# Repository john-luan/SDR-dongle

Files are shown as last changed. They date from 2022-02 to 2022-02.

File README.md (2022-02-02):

# Description
This PCB project was initially started as an exercise of learning KiCAD.  
这个PCB最初是作为学习KiCAD的练习开始的。  
And it is currently working with KiCAD 6.99.  
目前在KiCAD 6.99下进行工作。  
It is composed of a ZYNQ of 7z010 or 7z020, a AD936x RF transceiver, and some necessary peripheral circuits.  
它包含一个7z010或者7z020，一个AD936x收发器和一些必要的外围电路。  
Right now, the main layout is completed, but probably, there will still be some major changes in the future.  
现在主要部分的布线已经完成，但可能后续仍然会有大的改动。  
Due to the restriction of the layers, there remain some problems, such as trance across a split plane.  
受限于板层，还有一些问题比如布线跨分割。  
Subsequently I may need to do some FEM simulations, but I don't know how to export the KiCAD project to formats recognized by FEM tools.  
后续我可能需要做一些FEM模拟，但是目前为止我还不知道怎么将KiCAD的文件导出成FEM工具识别的格式。  
I can only do this with my spare time, so it will not be fast.  
我只能用业余时间做这件事，所以不会很快。  

# Goals
 - Matching Arduino MKR's size
 - Using a USB-C or USB micro B connector
 - As cheap as possible, avoiding complex craft like HDI or blind hole
 - Fan out pins as many as possible
 - DDR3 clock up to 1066
 - Boot by SD-Card
 - Compatible with the ADALM pluto Firmware
 - Compatible with Openwifi

# Things not done yet
 - Refactoring the format of schematics 
 - USB C master and slaver selection circuit
 - Simulation to ensure DDR signal Integrity performance
 - Test TPS2121 hot swap function
...

# Compromise
 - Transceiver data traces routing
 - USB HS signal reference plane too narrow
 - USB ULPI not be tuned (length difference <10mm)
 - LTCC balun instead of broadband balun, BLNK2-252R+(2.4-2.5GHz)/TCO1-462+(3.3-5.9GHz) seems OK
 - All DDR3 VREF is generated by different partial voltage resistors
 - Cannot meet the analog pin multiplexing function of Arduino. there is a suitable device AD5593R, there is no space to add the chip on this board, maybe this device can used at next major version
 - SD Card and USB connector shield is connected to GND
 - Router trace in DIP pin gap
 - USB PHY SPK Pin is connected to GND, beacause the bottom reference plane is splited in chip area. connect to GND to creating current return path.
 - ZYNQ boot configure pin is fixed, its means bank0 IO voltage cannot be set to 3.3V
 - Via in pad

Current img
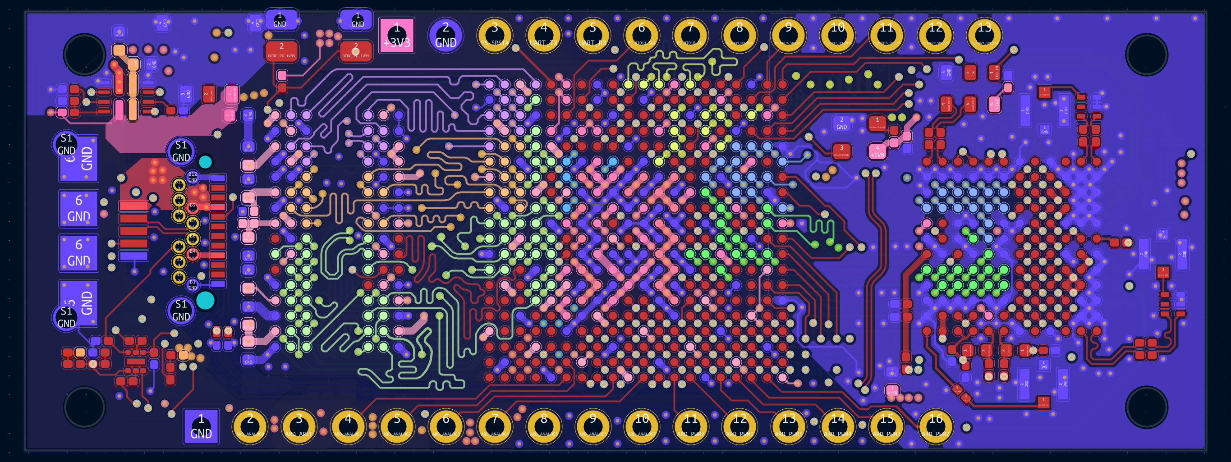
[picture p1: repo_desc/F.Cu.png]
F.Cu

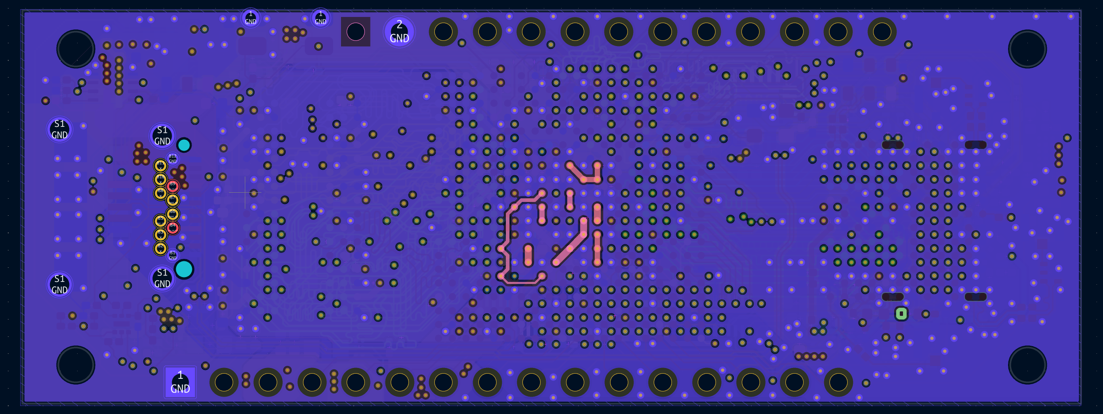
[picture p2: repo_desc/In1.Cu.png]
In1.Cu

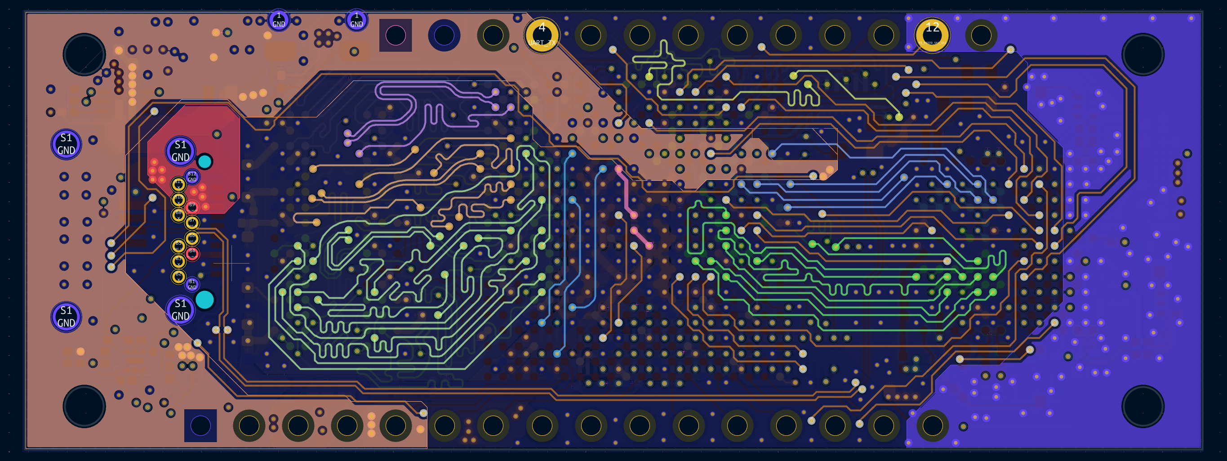
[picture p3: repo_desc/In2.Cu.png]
In2.Cu

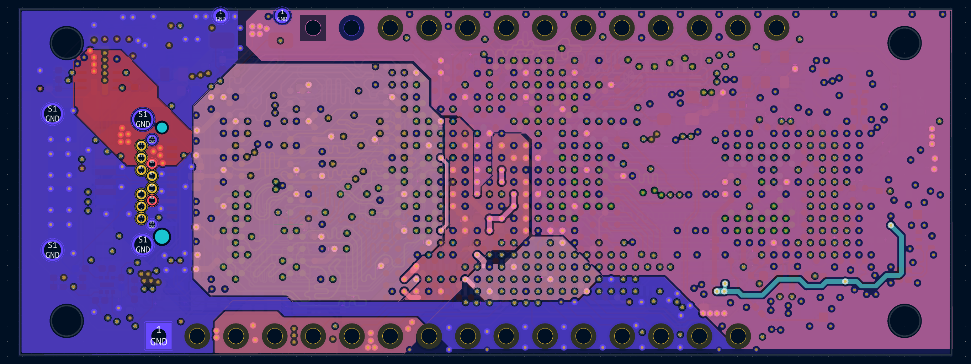
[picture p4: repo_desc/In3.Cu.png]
In3.Cu

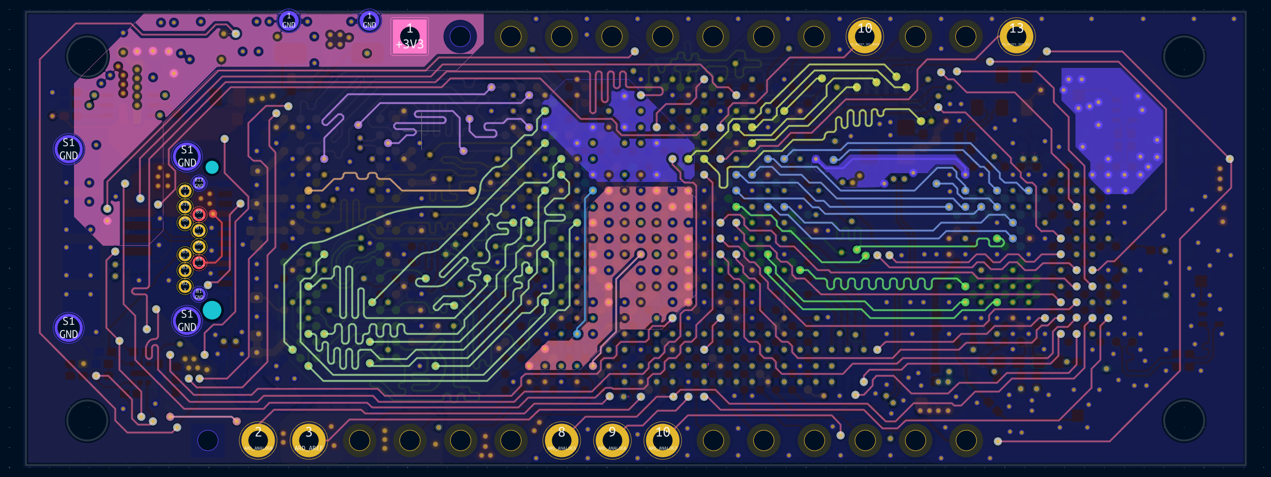
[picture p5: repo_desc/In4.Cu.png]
In4.Cu

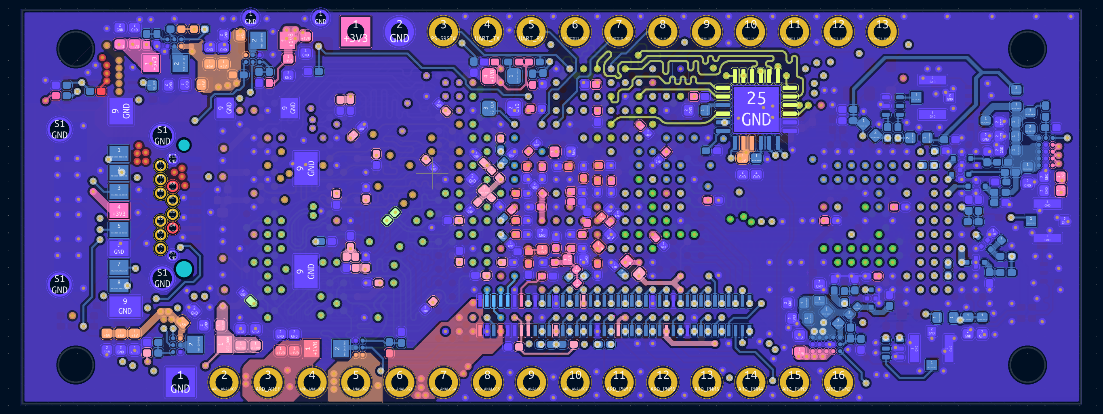
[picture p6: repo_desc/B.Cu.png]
B.Cu

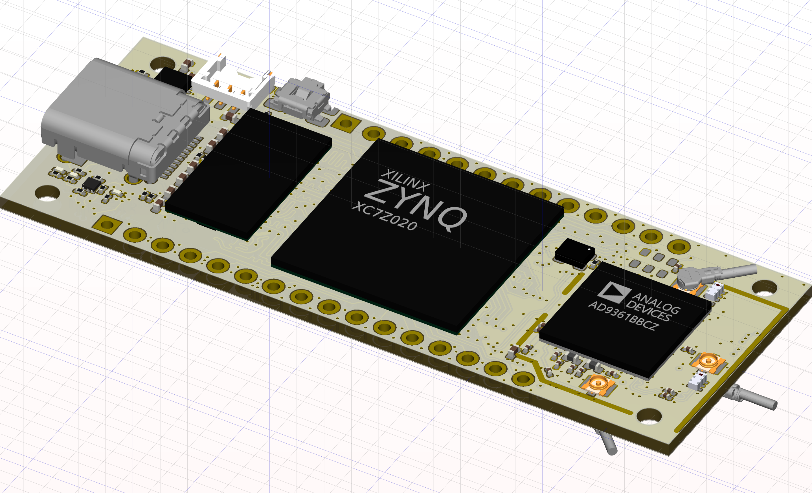
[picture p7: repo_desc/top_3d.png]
top_3D

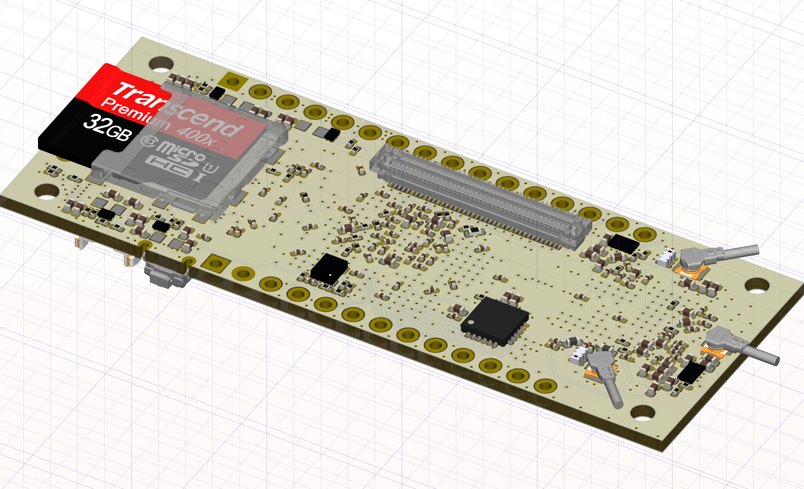
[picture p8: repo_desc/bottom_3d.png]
bottom_3d


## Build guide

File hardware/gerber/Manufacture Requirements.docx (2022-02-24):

# PCB工艺要求

层数：6

制作数量(拼板后)：20 pcs

最小线距 4mil；最小线宽 4mil

最小钻孔 0.2mm/0.4mm

钻孔类型：通孔

钻空孔处理方式：树脂塞孔表面镀平

孔壁铜厚：满足IPC 2级标准(min 18um; typ 20um)

表面处理：沉金

阻焊颜色：黑色亚光

丝印颜色：默认(白色)

阻焊桥处理：厂家根据实际加工能力可以不做小于工艺能力的阻焊桥，需要在工程确认时对光绘文件改动进行确认。

PCB尺寸（拼板后）：75.3mm×94.2mm

测试

四线过孔测试，飞针测试，通断测试等常规测试

提供出货报告

公差

板厚公差：±10%

板外形公差：±0.1mm

翘曲度（整版，以对角线参考）：≤1%

设计文件格式：Gerber文件

Gerber文件板层顺序和层压结构：

Gerber文件名 | 层功能描述/板材 | 厚度
xxx_Edge_Cuts.gbr | 工艺层:PCB外框
xxx_F_Silkscreen.gbr | 工艺层:顶层丝印 | | 3，4
xxx_F_Mask.gbr | 工艺层:顶层阻焊层掩膜 | 约1mil
xxx_F_Cu.gbr | 顶层铜层 | 1Oz | 完成铜厚>35um
Prepreg | 介质层/FR4 | 0.1mm | 1, 2
xxx_In1_Cu.gbr | 内部铜层 | 1Oz
Core | 介质层/FR4 | 0.2mm | 1, 2
xxx_In2_Cu.gbr | 内部铜层 | 1Oz
Prepreg | 介质层/FR4 | 0.127 | 1, 2
xxx_In3_Cu.gbr | 内部铜层 | 1Oz
Core | 介质层/FR4 | 0.2mm | 1, 2
xxx_In4_Cu.gbr | 内部铜层 | 1Oz
Prepreg | 介质层/FR4 | 0.1mm | 1, 2
xxx_B_Cu.gbr | 底层铜层 | 1Oz | 完成铜厚>35um
xxx_B_Mask.gbr | 工艺层:底层阻焊层掩膜 | 约1mil
xxx_B_Silkscreen.gbr | 工艺层:底层丝印 | | 3，4
总厚度 | | 1mm

1. 实际层压可以根据工艺微调，并在工程确认中反馈
2. 需要在工程确认中确认实际使用板材种类
3. 请勿在丝印层上添加厂家丝印，客编等源Gerber中没有的图形
4. 如果有丝印层和阻焊层开窗冲突的，去除冲突部分丝印层图案

钻孔文件：

xxx_NPTH.drl – NPTH钻孔

xxx_PTH.drl – PTH钻孔

xxx_NPTH_map.ps – NPTH钻孔描述

xxx_PTH_map.ps – PTH钻孔描述

钢网使用无边框钢片，将拼板后正反面（B_Paste层，F_Paste层）拼在同一张钢网上

钢网文件：

xxx_B_Paste - 底层钢网

xxx_F_Paste - 顶层钢网

拼板：

Gerber文件需要按板框标识层进行拼板，每4个单元板构成一个拼板。

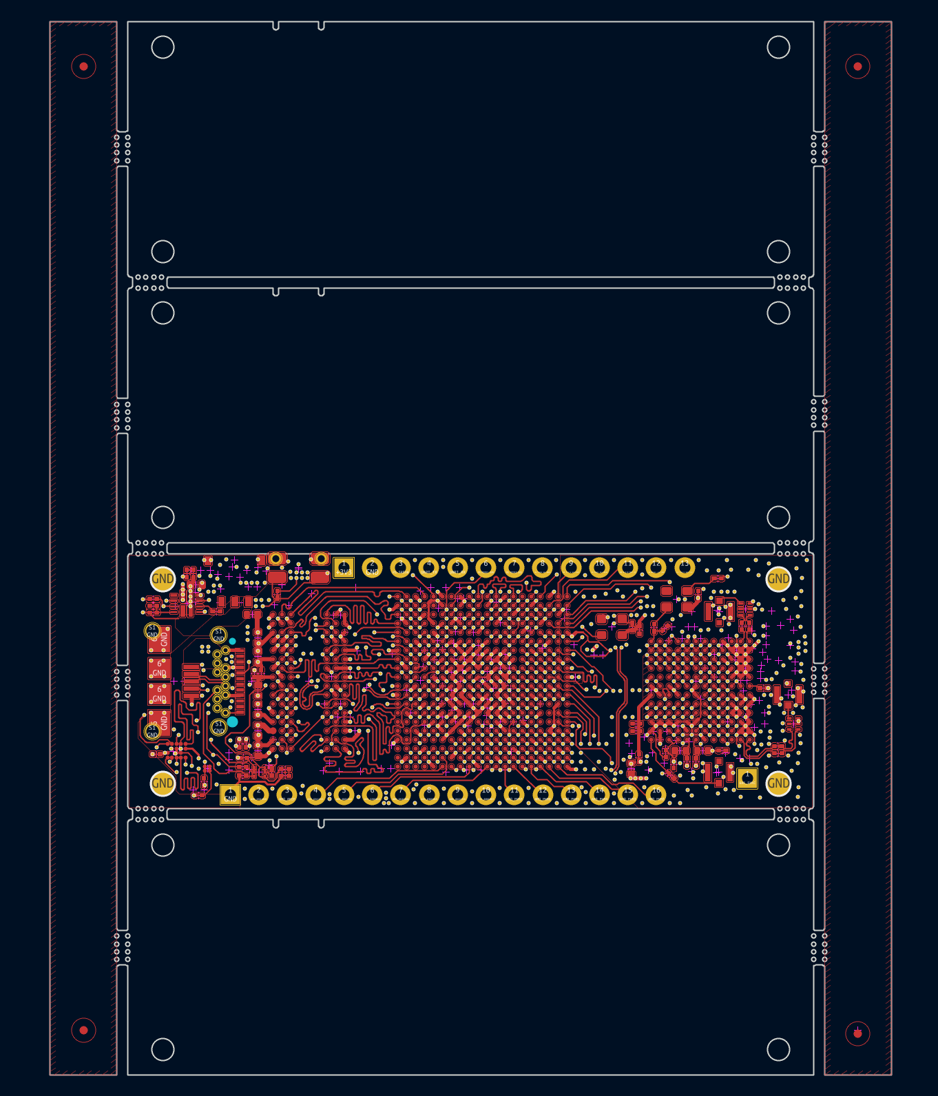
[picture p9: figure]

备注：

接受拼板打叉板，但需要按子板单元总数满足数量要求

需要工程/光绘确认完毕后再开料生产

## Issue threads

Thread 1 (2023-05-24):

咨询

ZhuYanzhen1, 2023-05-24:
请问此仓库中的电路有测试过吗，是否可以使用呢

john-luan, 2023-10-12:
> 请问此仓库中的电路有测试过吗，是否可以使用呢

R2是DDR RST的上拉，和SD座子冲突。但是实测DDR可以起。
C38要NC，不然可能RST后时序不对PS不启动。
MAX38904C买不到，TPS2121买不到
巴伦封装太小了，只能用LC巴伦，做不到高调谐带宽。

Linux能起，USB能读到，AD9361能读到。
9361 的移植没有做，要用的话需要检查CMOS连线和想办法做射频的测试。我自己review应该没啥问题

Closed 2023-10-12.

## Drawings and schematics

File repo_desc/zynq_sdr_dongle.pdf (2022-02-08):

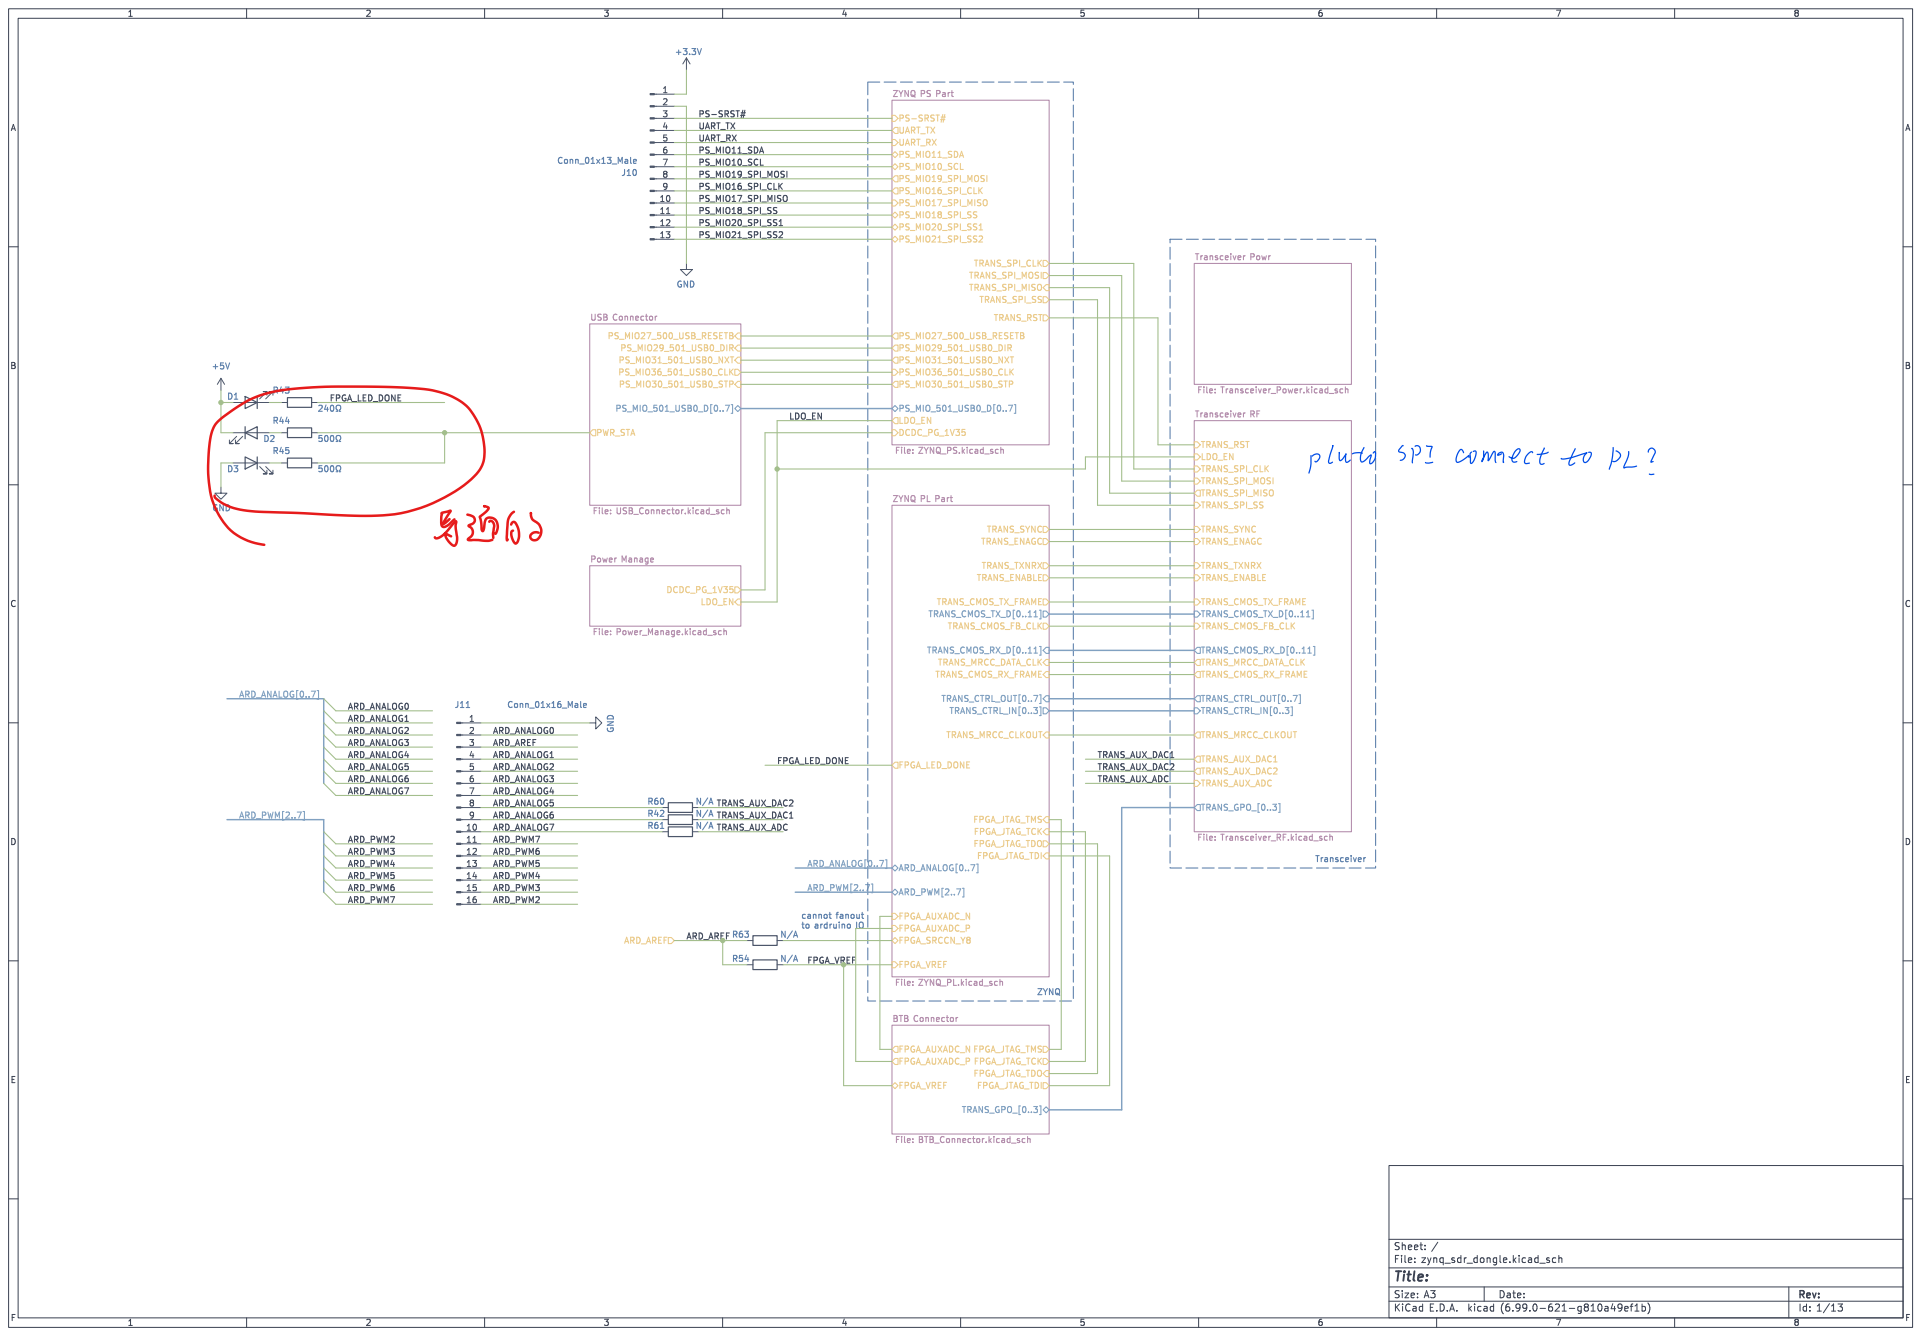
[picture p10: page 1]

PS_MIO27_500_USB_RESETB
ZYNQ PL Part File: ZYNQ_PL.kicad_sch FPGA_VREF

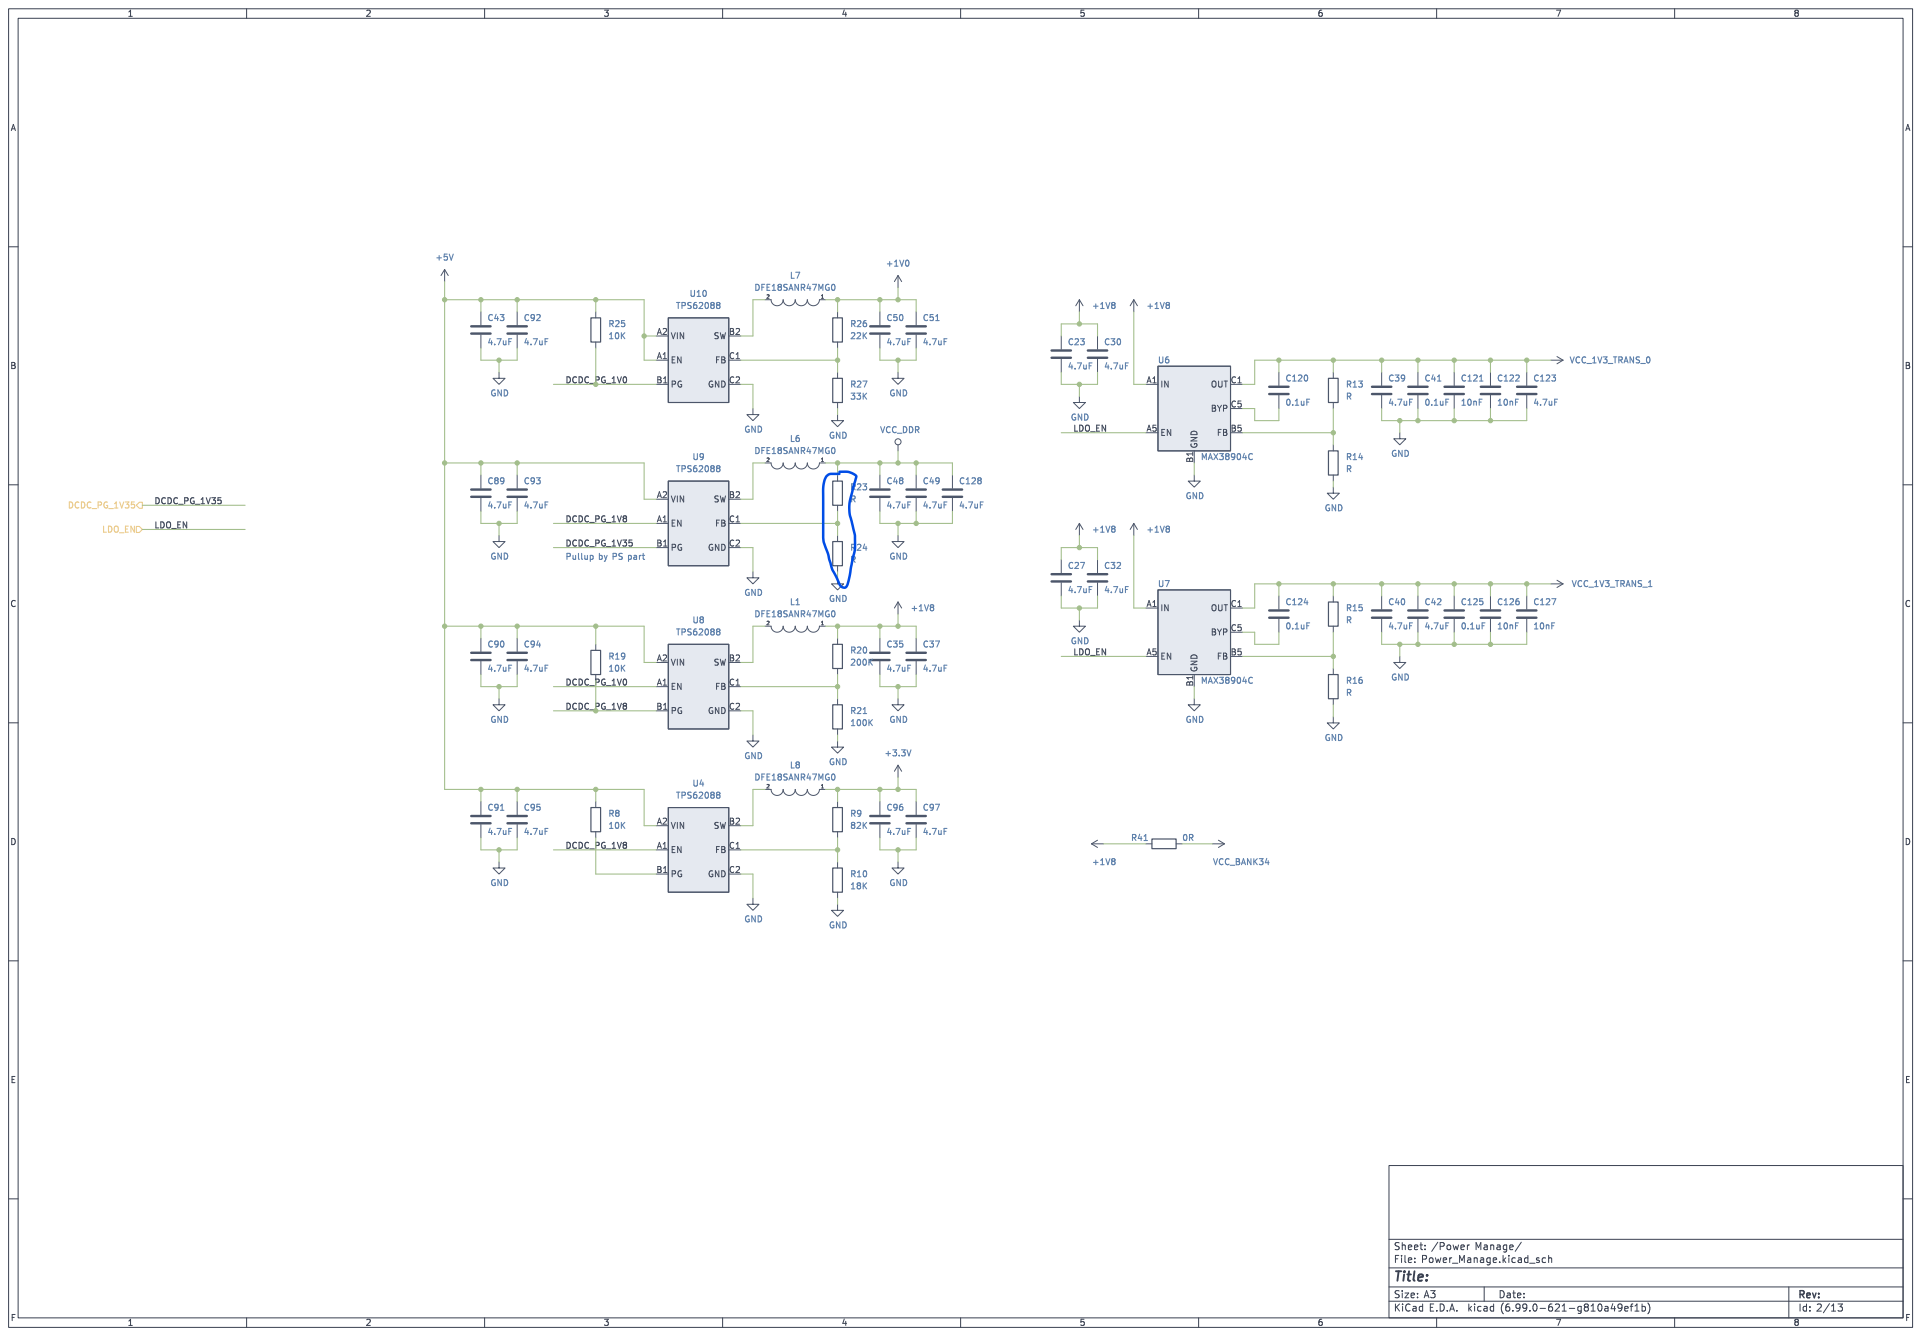
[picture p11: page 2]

Pullup by PS part

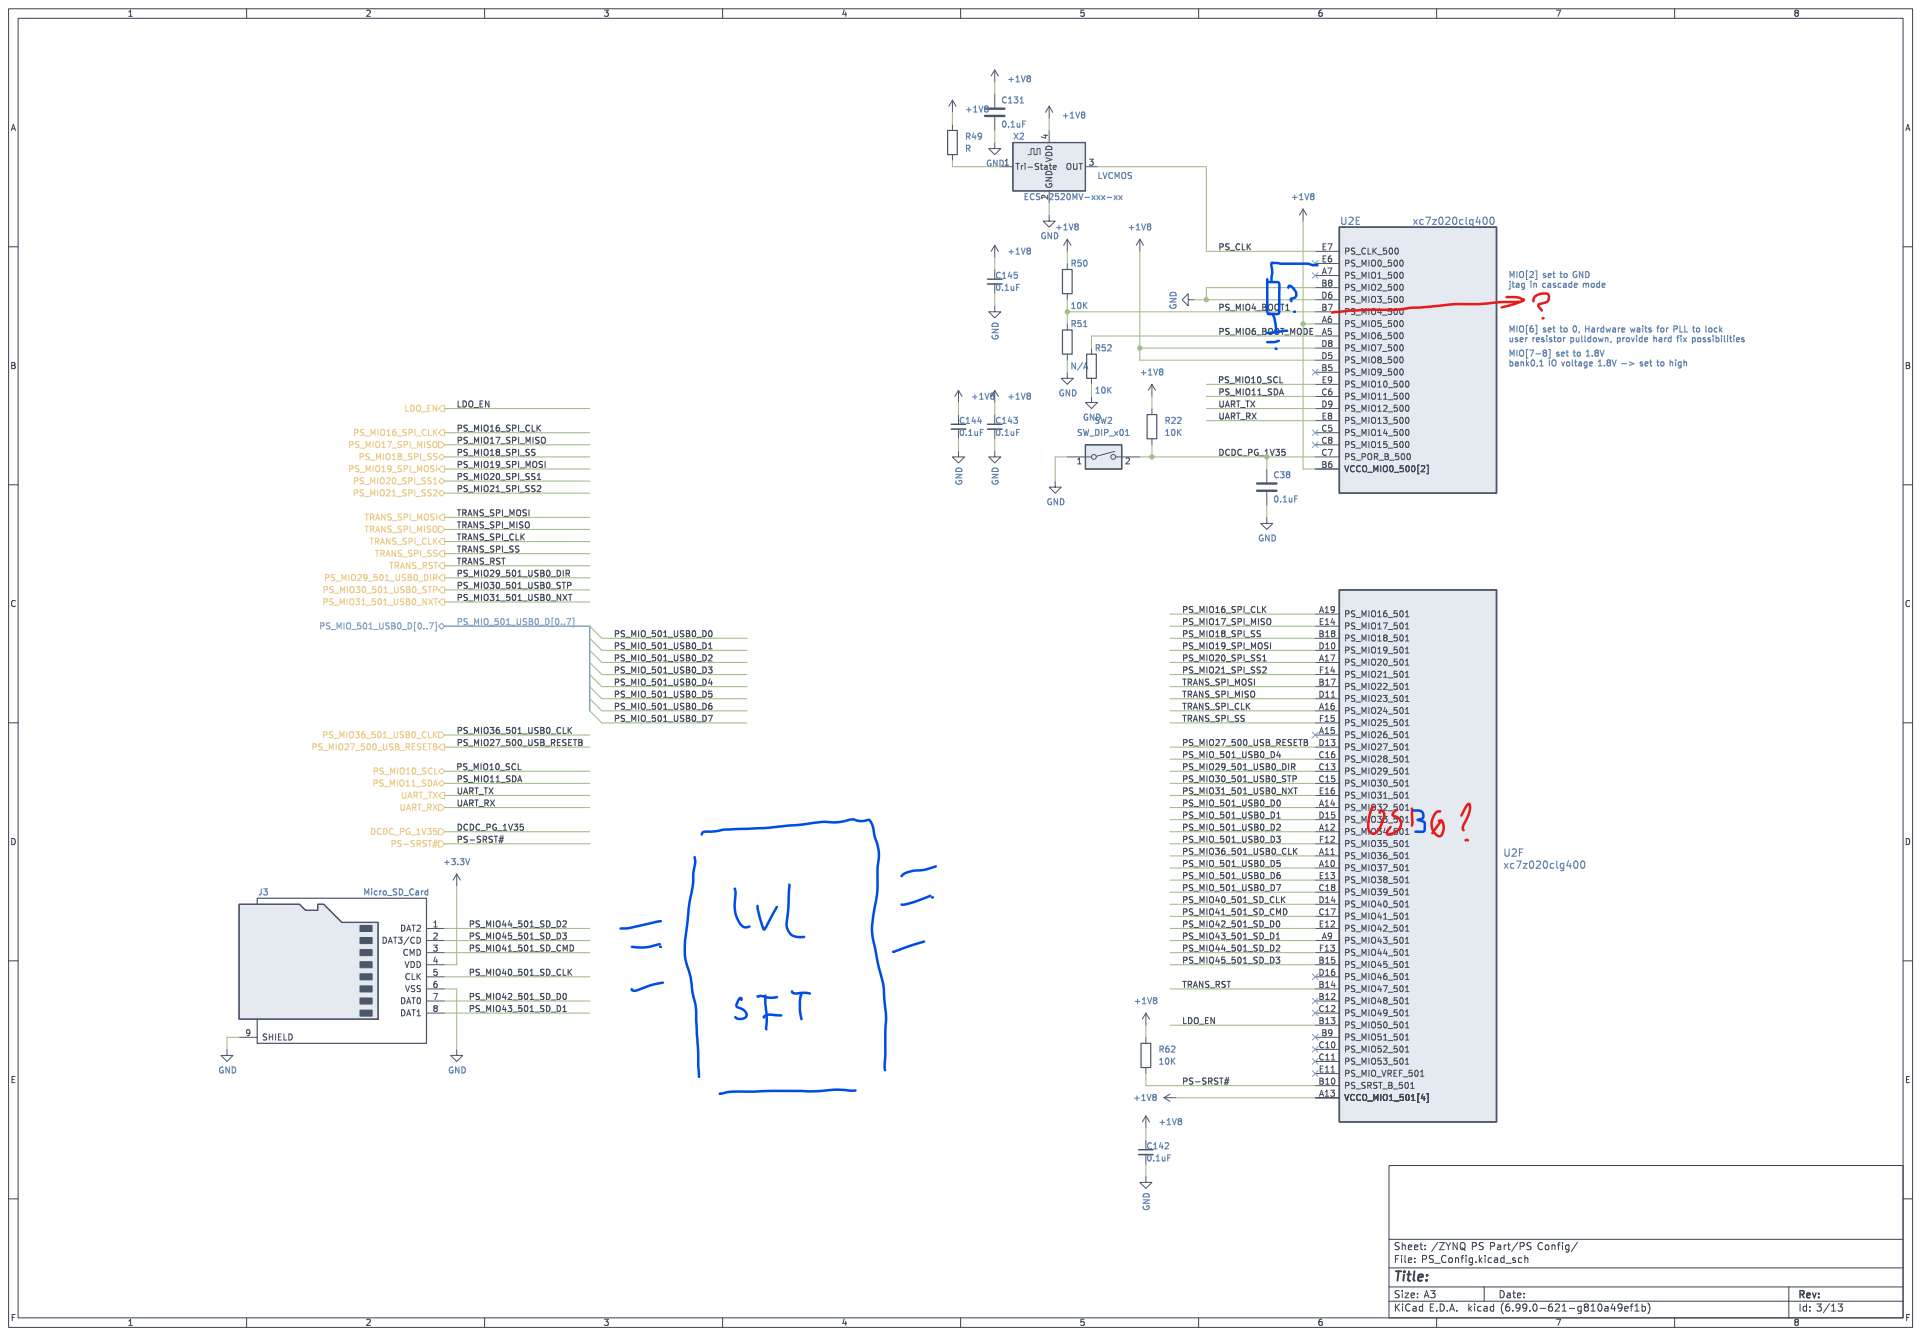
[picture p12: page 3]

MIO[2] set to GND
jtag in cascade mode

user resistor pulldown, provide hard fix possibilities
MIO[7-8] set to 1.8V
bank0,1 IO voltage 1.8V -> set to high

Sheet: /ZYNQ PS Part/PS Config/
File: PS_Config.kicad_sch
Id: 3/13 Title:

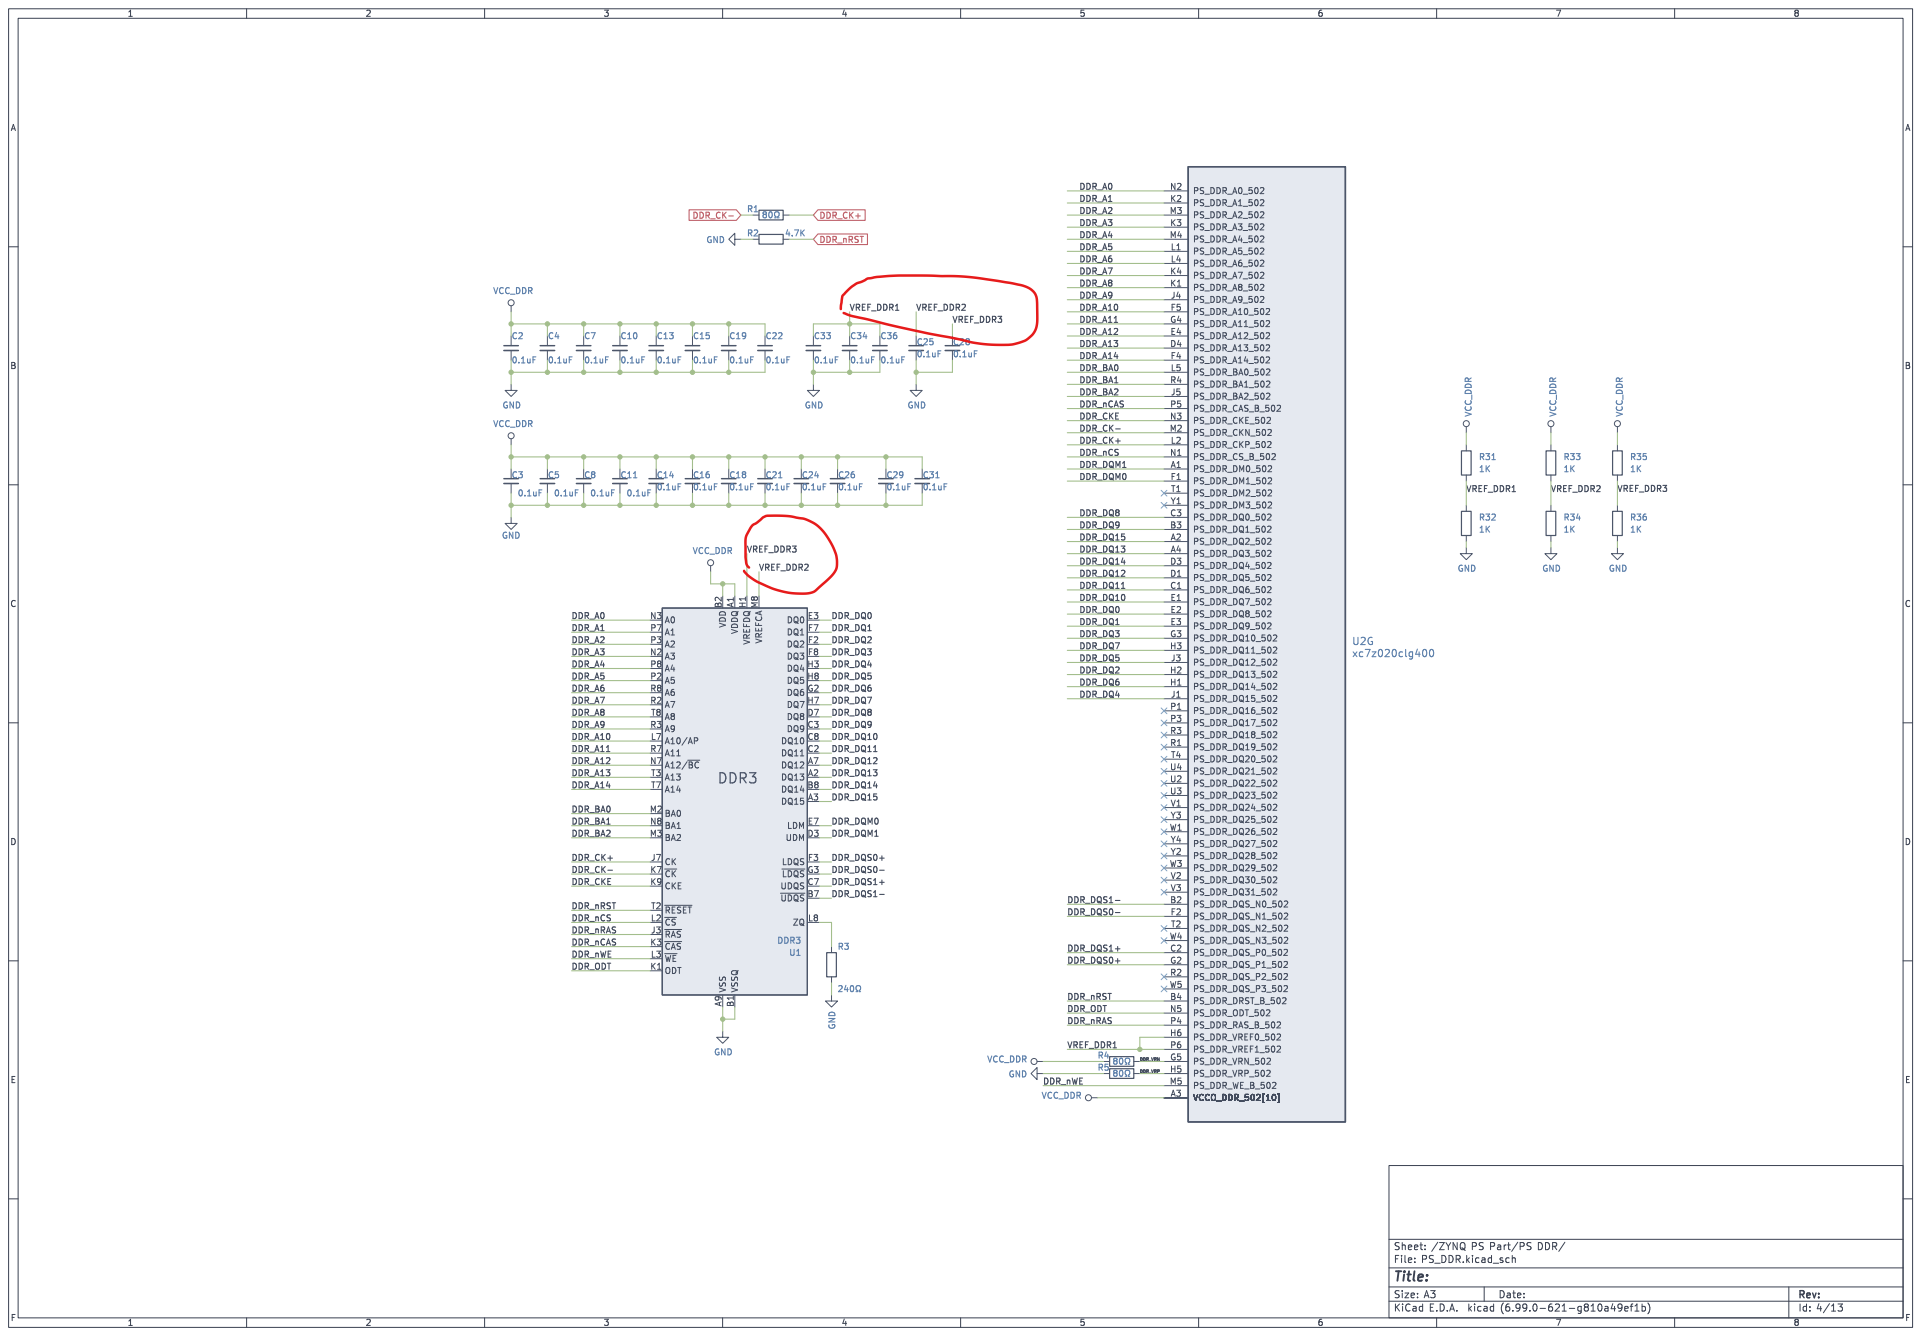
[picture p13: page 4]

Sheet: /ZYNQ PS Part/PS DDR/
File: PS_DDR.kicad_sch
Id: 4/13 Title:

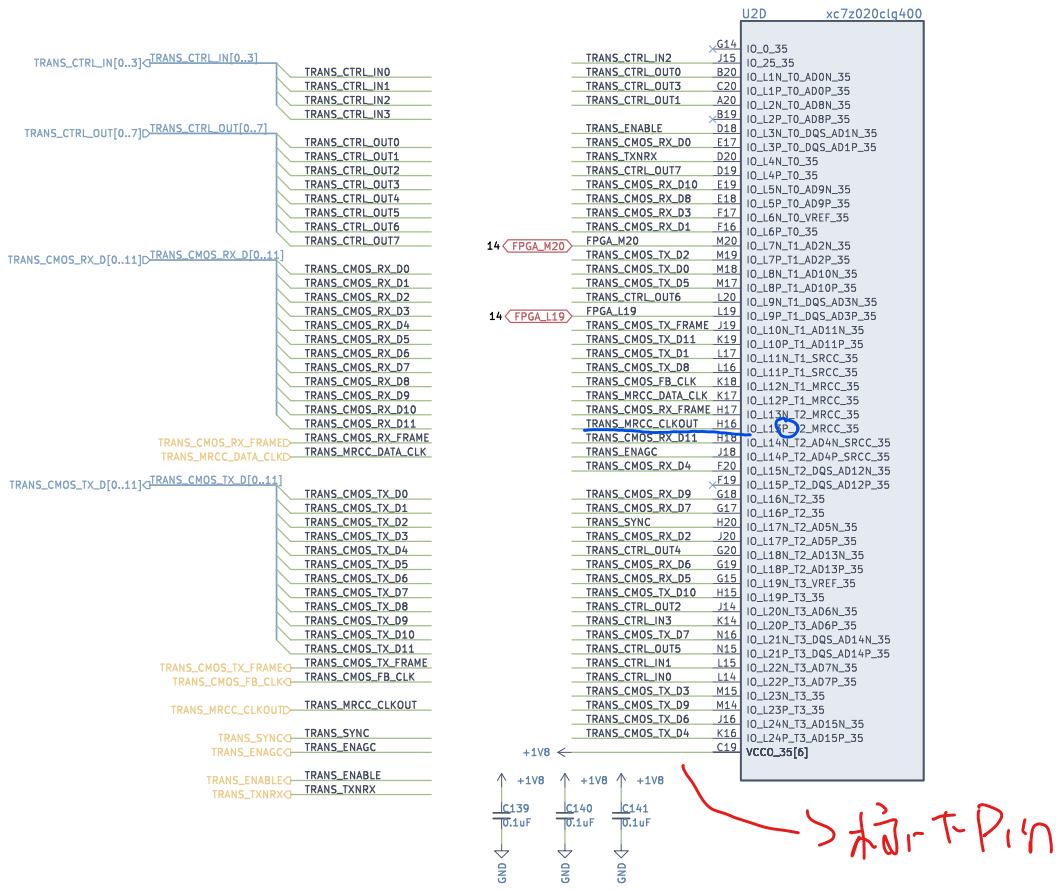
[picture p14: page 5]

Sheet: /ZYNQ PL Part/PL Transceiver/ GND

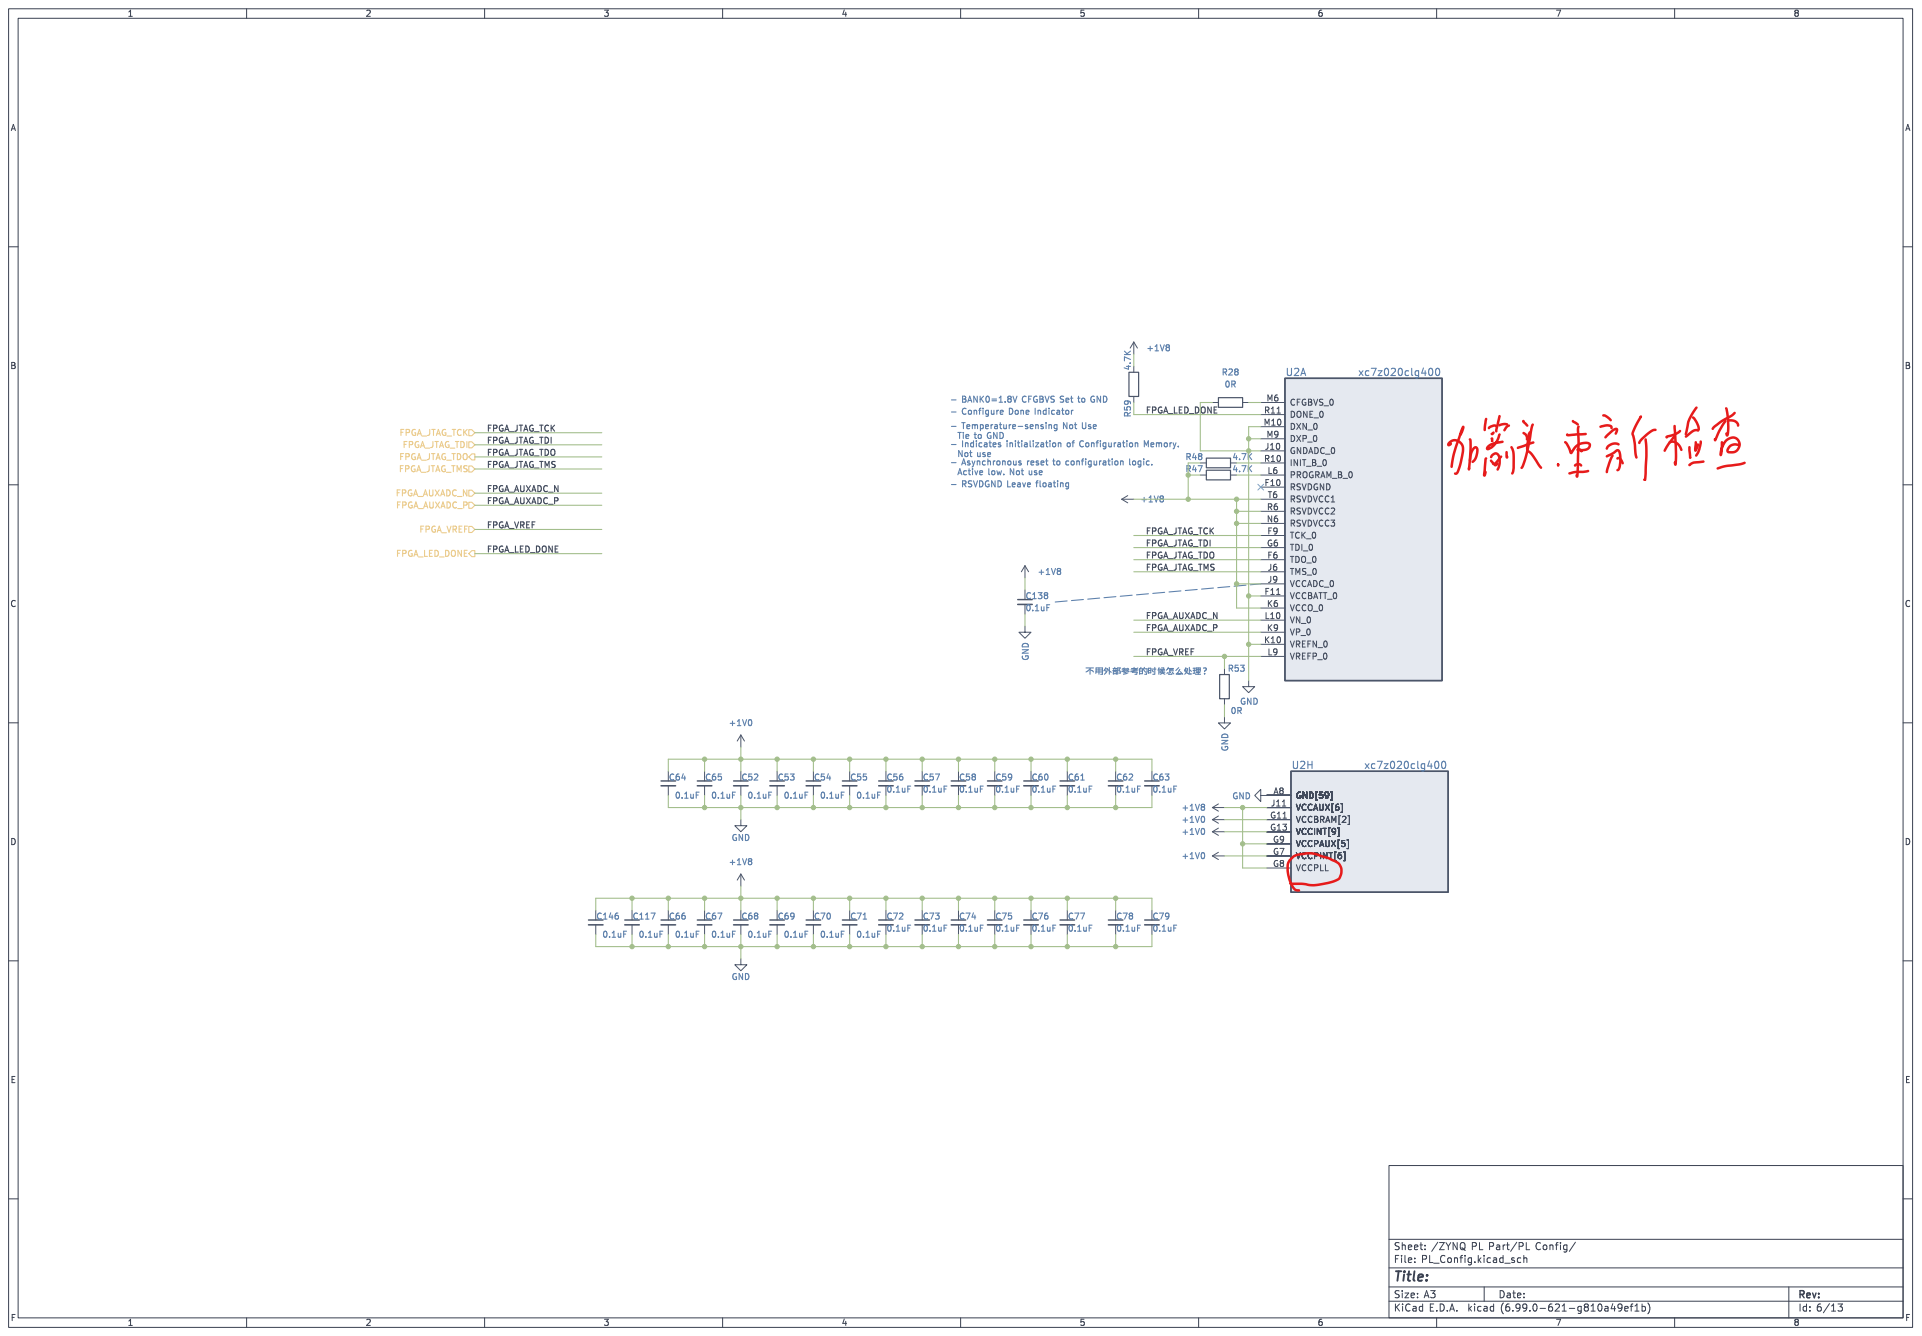
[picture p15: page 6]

- BANK0=1.8V CFGBVS Set to GND
- Configure Done Indicator
- Temperature-sensing Not Use
Tie to GND
- Indicates initialization of Configuration Memory.
Not use
- Asynchronous reset to configuration logic.
Active low. Not use
- RSVDGND Leave floating

Sheet: /ZYNQ PL Part/PL Config/
File: PL_Config.kicad_sch
Id: 6/13 Title:

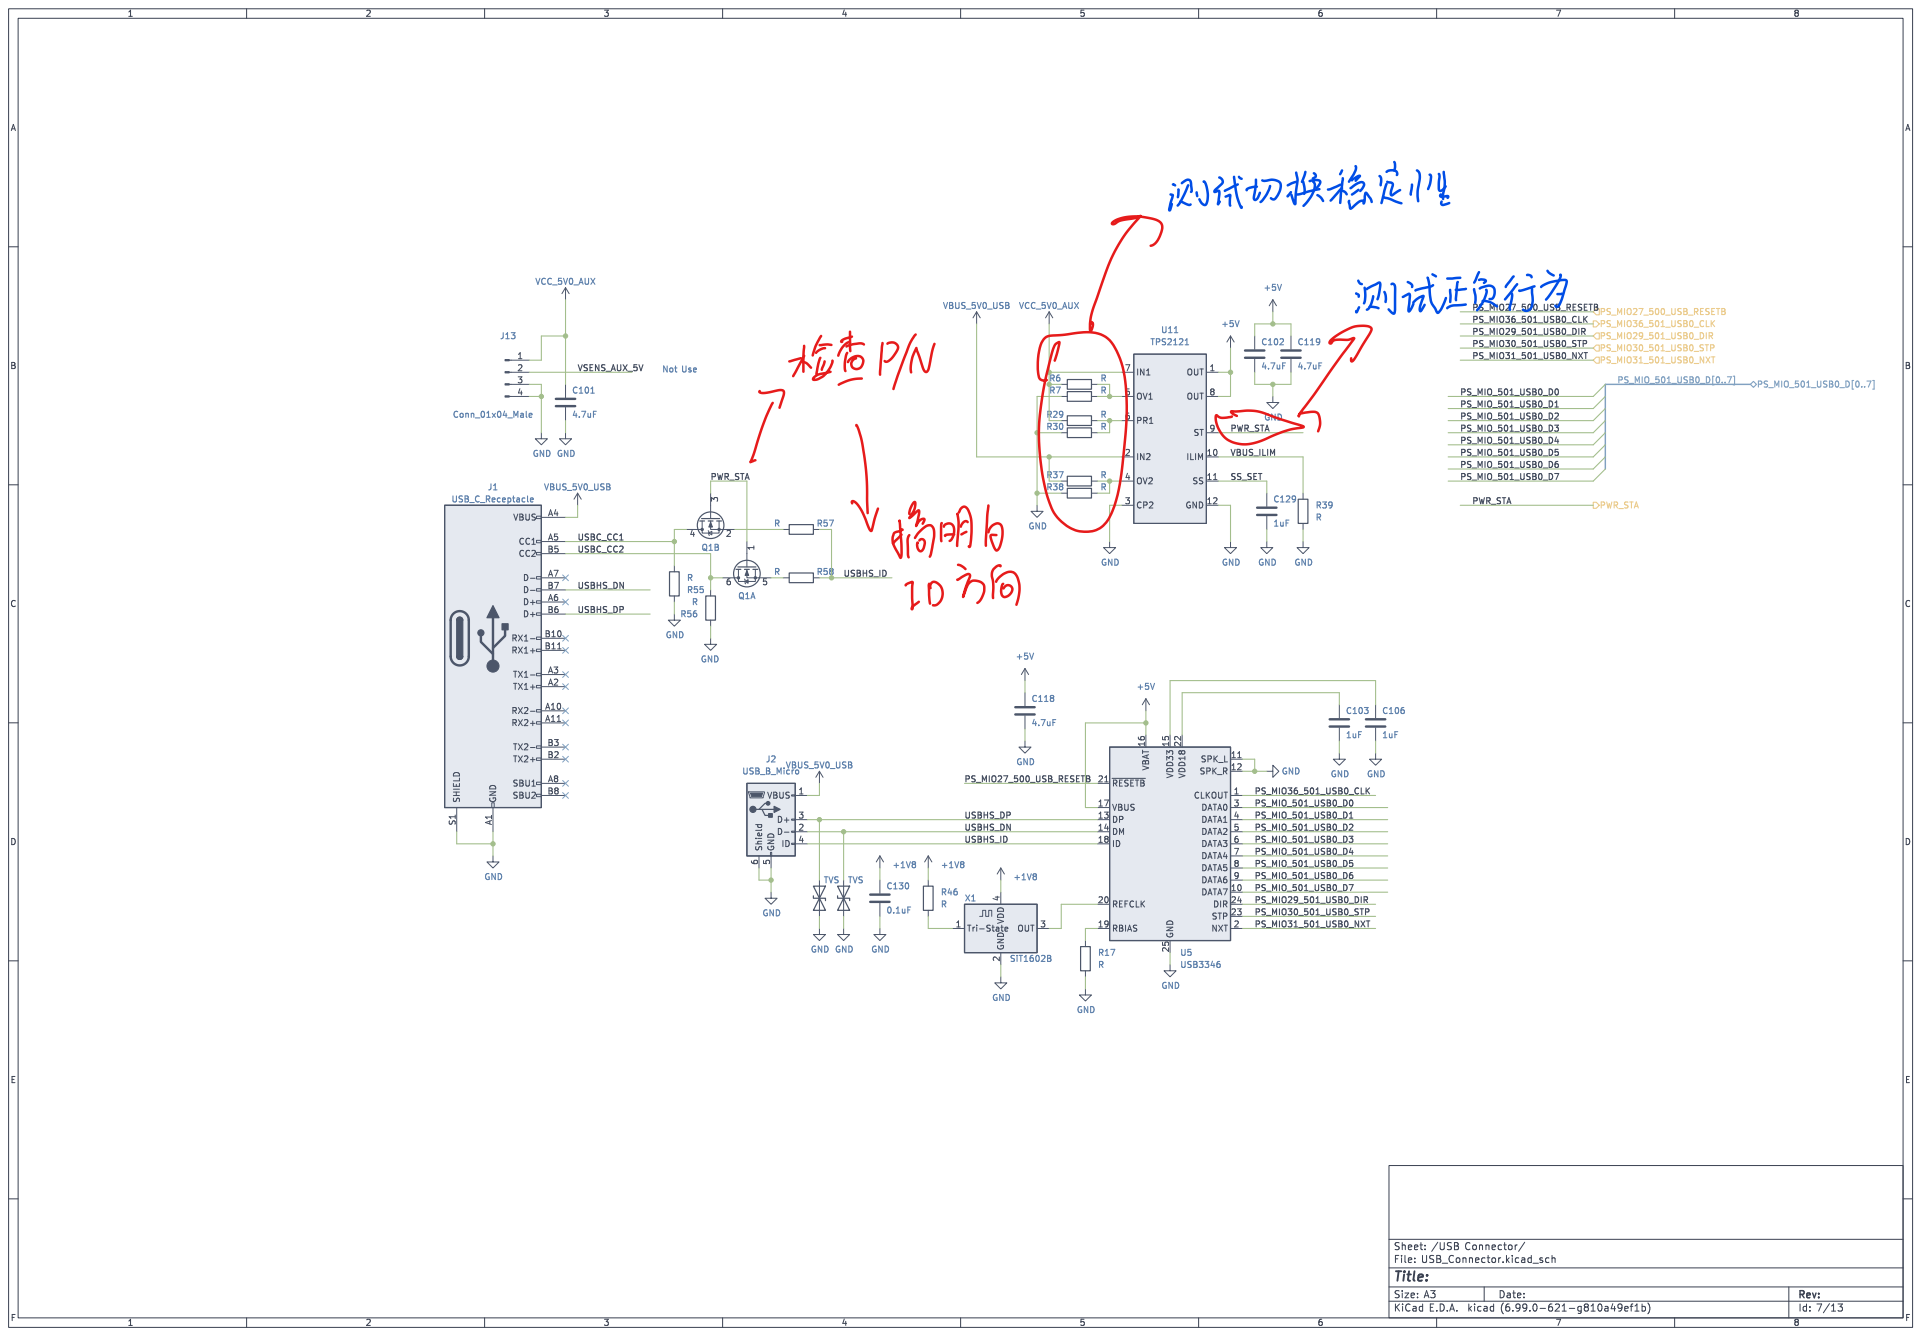
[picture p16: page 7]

2 OUT VDD 3 X1 4 SiT1602B GND GND GND GND

File: USB_Connector.kicad_sch Sheet: /USB Connector/

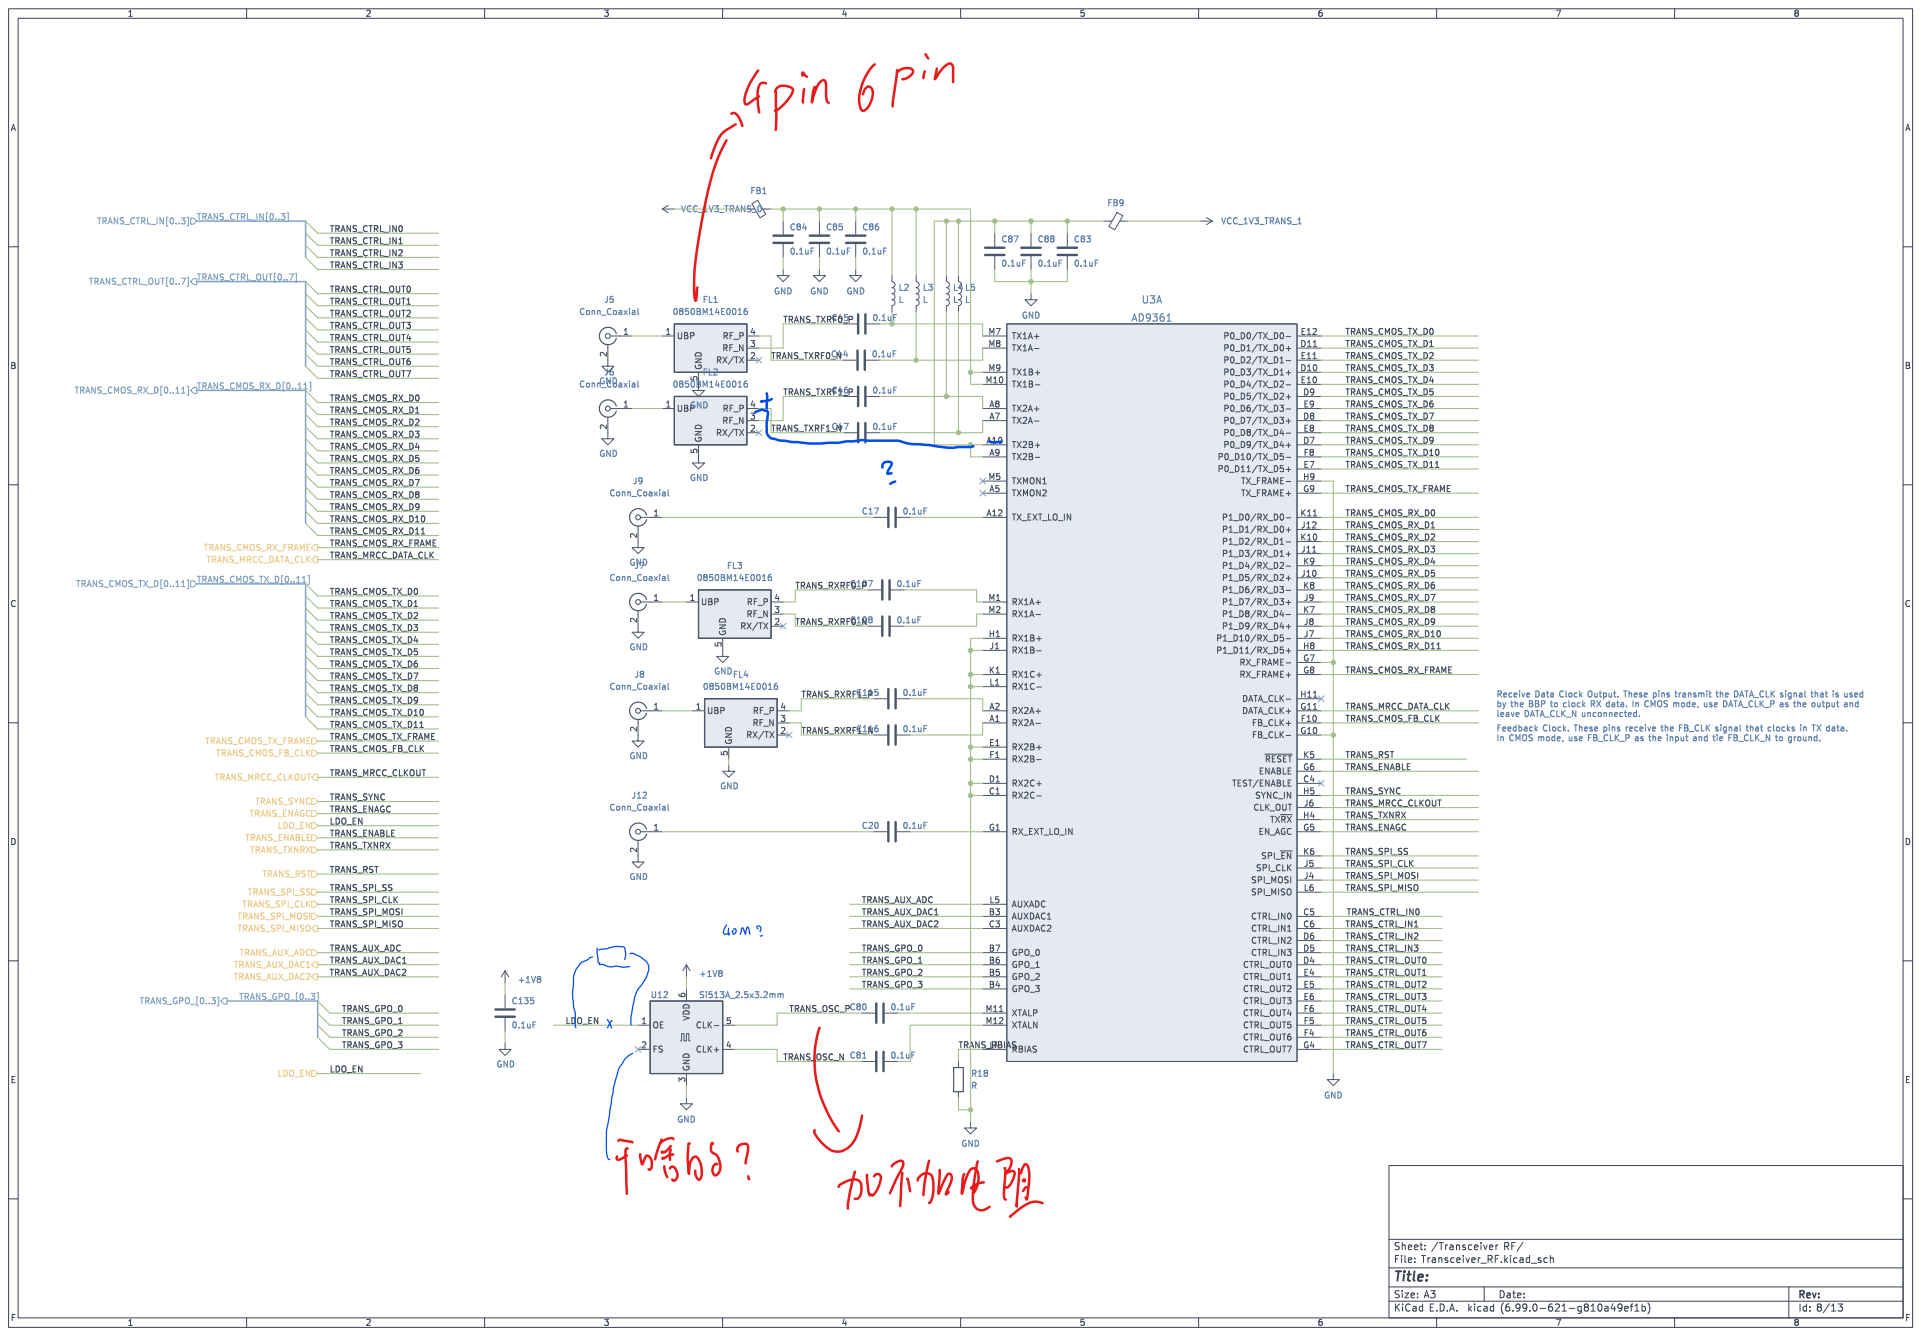
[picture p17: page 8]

2 J7 Conn_Coaxial UBP 1 RX/TX 2 RF_N 3 RF_P 4 GND

Receive Data Clock Output. These pins transmit the DATA_CLK signal that is used
by the BBP to clock RX data. In CMOS mode, use DATA_CLK_P as the output and
leave DATA_CLK_N unconnected.
TRANS_CTRL_OUT1 TRANS_SYNC
TRANS_MRCC_CLKOUT
TRANS_TXNRX
TRANS_SPI_MOSI TRANS_ENAGC

In CMOS mode, use FB_CLK_P as the input and tie FB_CLK_N to ground.

File: Transceiver_RF.kicad_sch Sheet: /Transceiver RF/

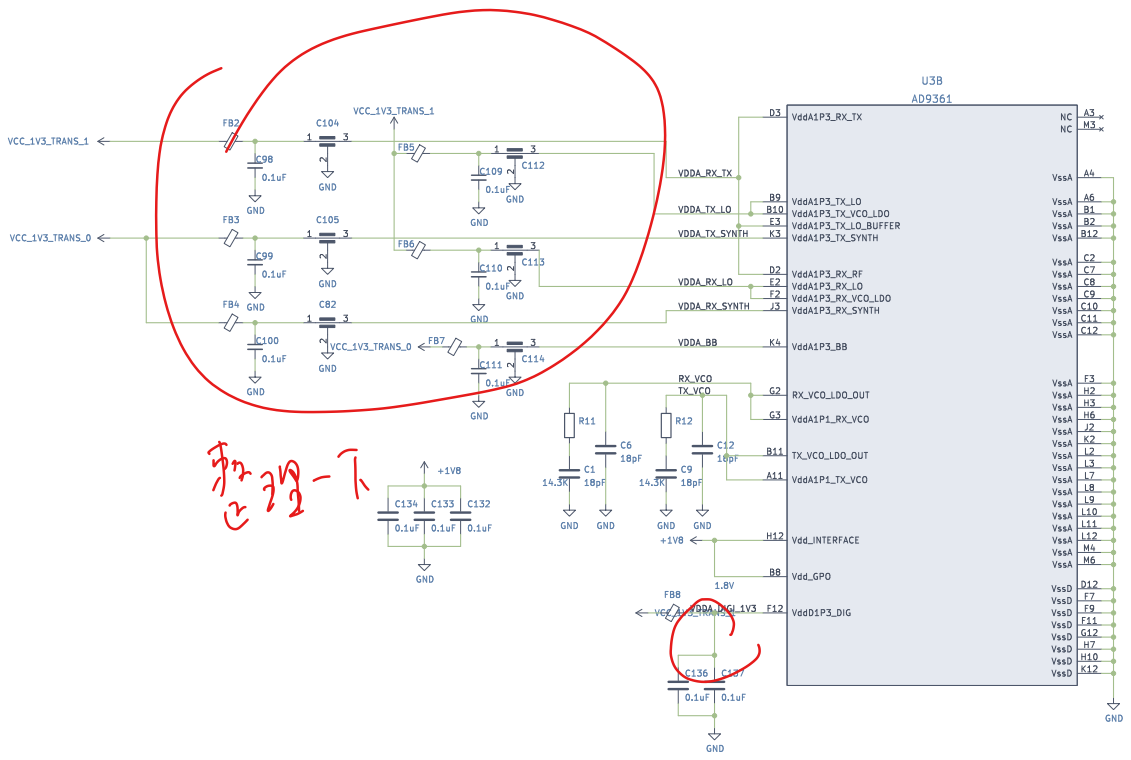
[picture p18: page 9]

File: Transceiver_Power.kicad_sch Sheet: /Transceiver Powr/

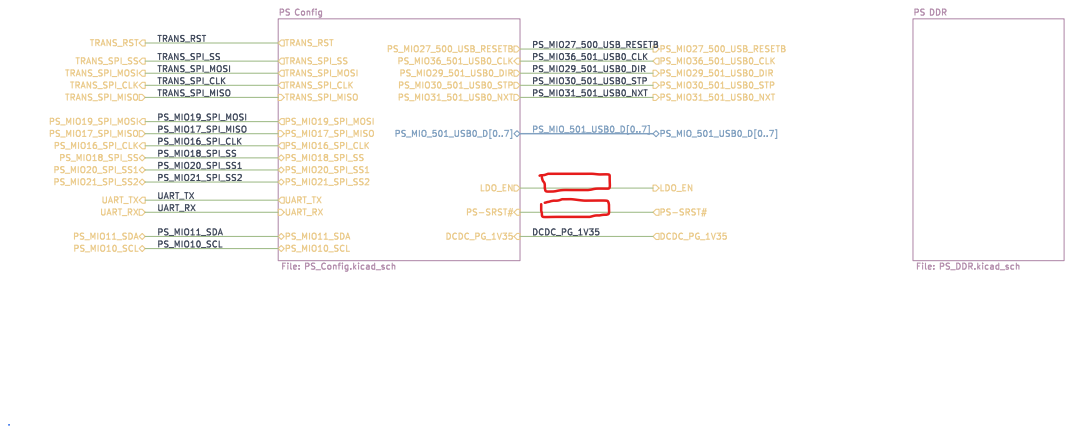
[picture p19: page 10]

Sheet: /ZYNQ PS Part/
File: ZYNQ_PS.kicad_sch
Id: 11/13 Title:

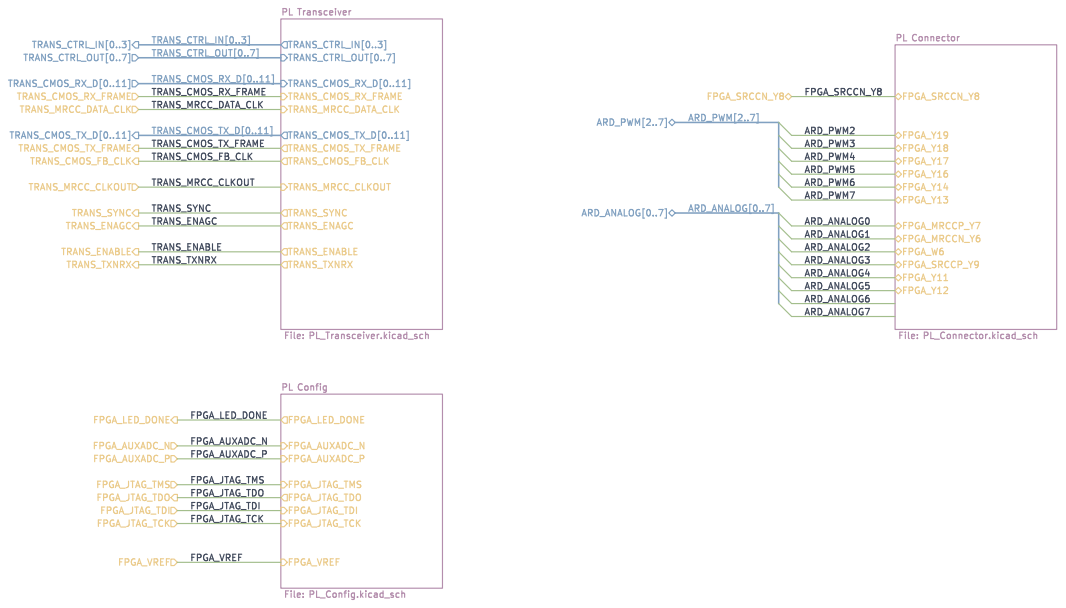
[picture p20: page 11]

Sheet: /ZYNQ PL Part/
File: ZYNQ_PL.kicad_sch
Id: 12/13 Title:

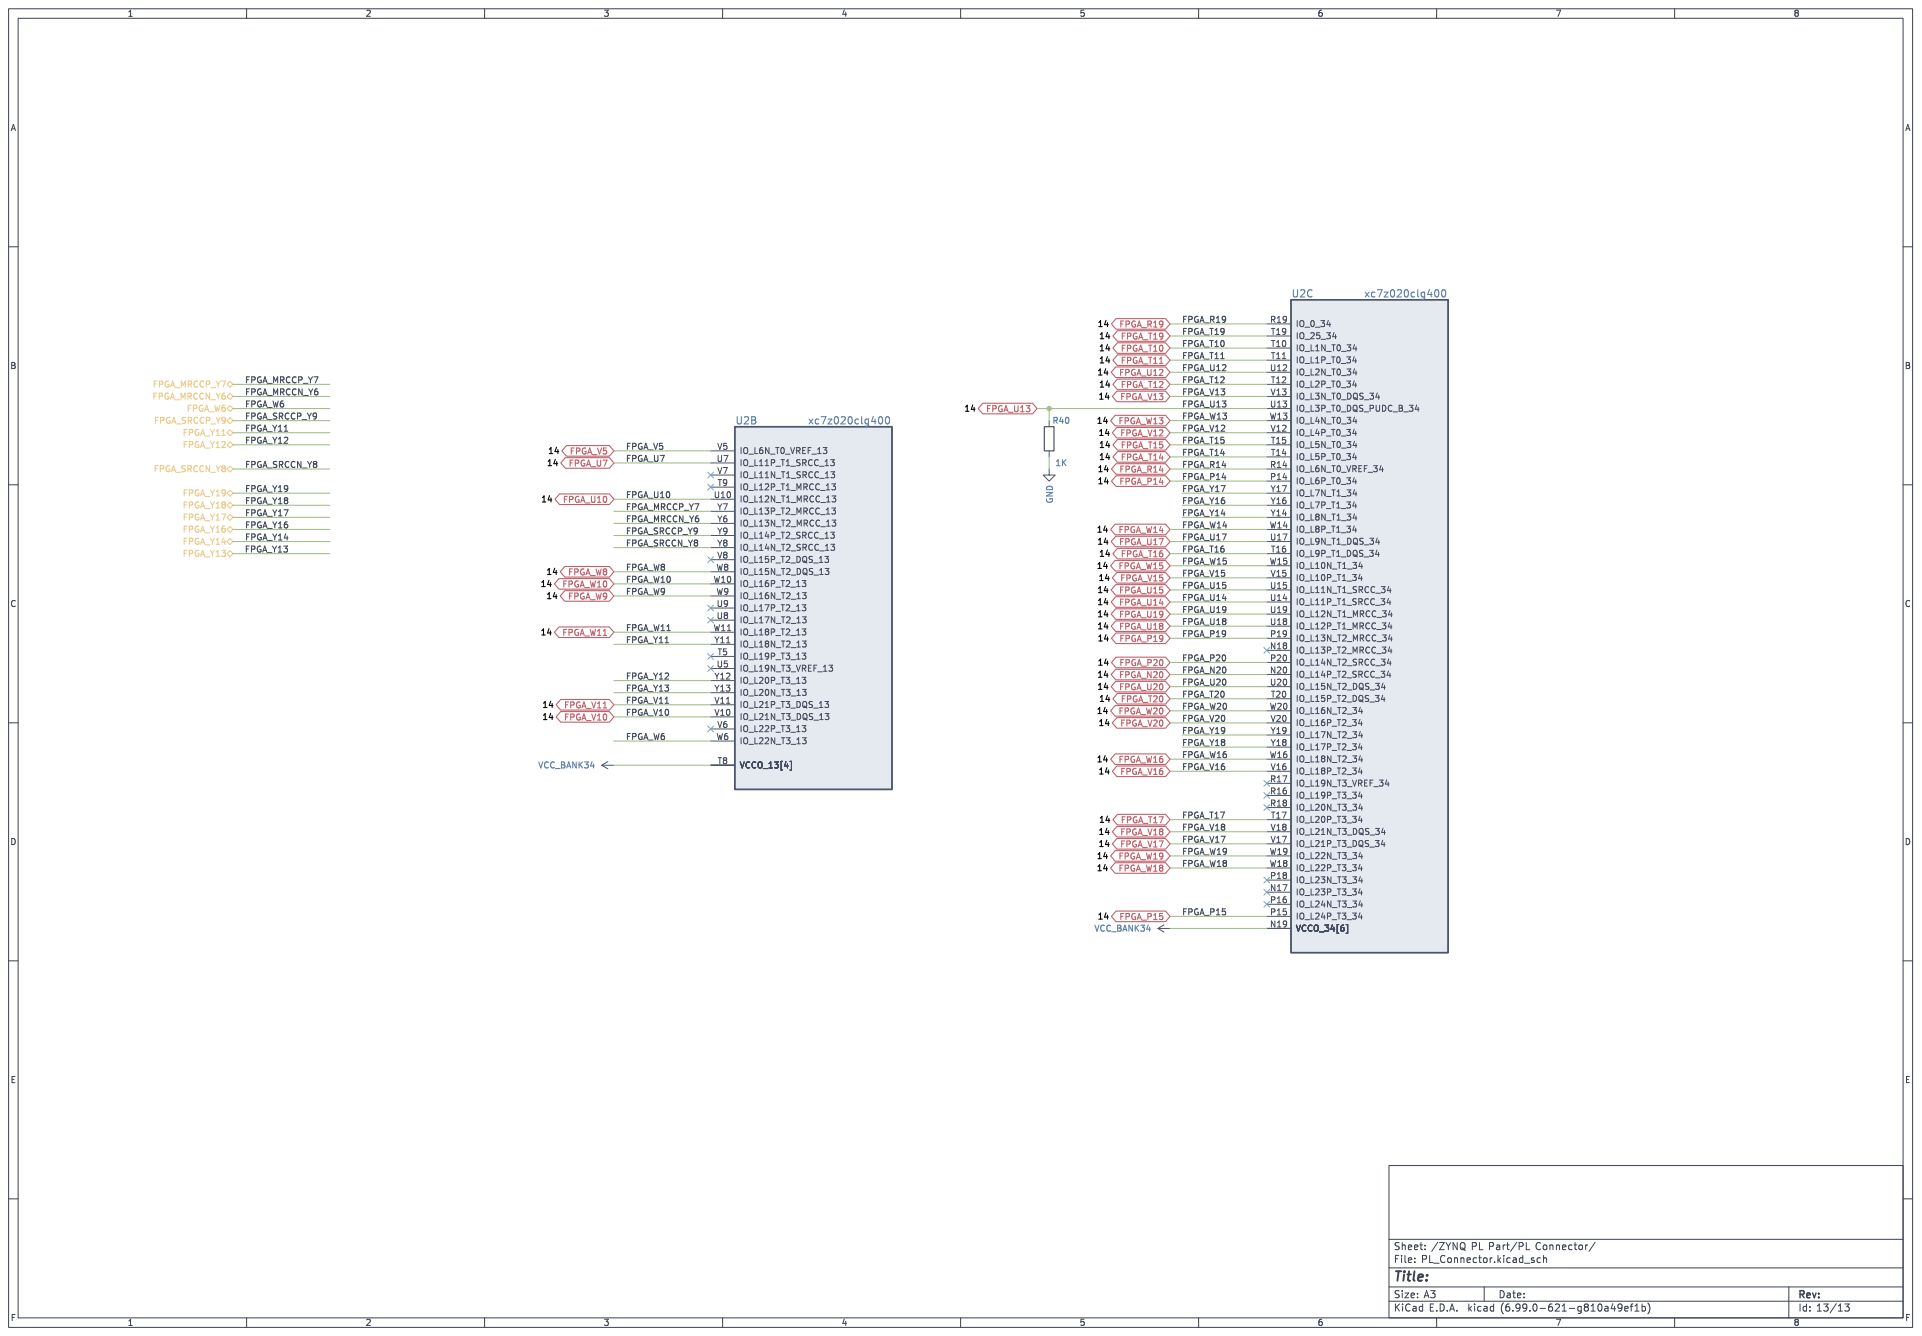
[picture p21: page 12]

Sheet: /ZYNQ PL Part/PL Connector/
File: PL_Connector.kicad_sch
Id: 13/13 Title:


File: BTB_Connector.kicad_sch Sheet: /BTB Connector/ GND

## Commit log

2022-01-03 Initialize repositories Add README documentation Add screenshots of the current PCB status
    [zynq_sdr_dongle.kicad_sch]
2022-01-08 7z010 and 7z020 DDR pin delay in package different!? Re-layout WE and CKE signal which are on B.Cu layer to inner layer. All the DDR3 signal referred to integral plane Change over-voltage protector f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
2022-02-02 Add USB ESD diode Revise DDR3 DQS0 polarity. ZYNQ can only be booted by SDIO which located MIO[40..45], correspondly change USB PHY MIO to MIO[28..39]. Add USB CC Control Logic Refactoring Schematic 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
    [BTB_Connector.kicad_sch, PL_Config.kicad_sch, PL_Connector.kicad_sch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]
2022-02-08 add sdio level shift ciruit
    [BTB_Connector.kicad_sch, PL_Config.kicad_sch, PL_Connector.kicad_sch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]
2022-02-09 Add PS I2C pullup resistor
    [PS_Config.kicad_sch, Transceiver_RF.kicad_sch, zynq_sdr_dongle.kicad_sch]
2022-02-24 Modify wrong DCDC TPS62088 package Panelize PCB Add manufacture requirements files
    [PL_Config.kicad_sch, PS_Config.kicad_sch, PS_DDR.kicad_sch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]
